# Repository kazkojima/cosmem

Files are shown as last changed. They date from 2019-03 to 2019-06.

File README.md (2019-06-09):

# cosmem

cosmem is a simple RAM/ROM/clock generator for COSMAC 1802 CPU, implemnted with TinyFPGA. An ancient chip meets FPGA :-)

spimemio.v is imported from the picorv32 example written by Clifford Wolf.

[board]

lv3v3/ is for kicad files of a level shifter board to interface 1802 and TinyFPGA.

picture of cosmaclv

within this enclosure

picture of cosmac box

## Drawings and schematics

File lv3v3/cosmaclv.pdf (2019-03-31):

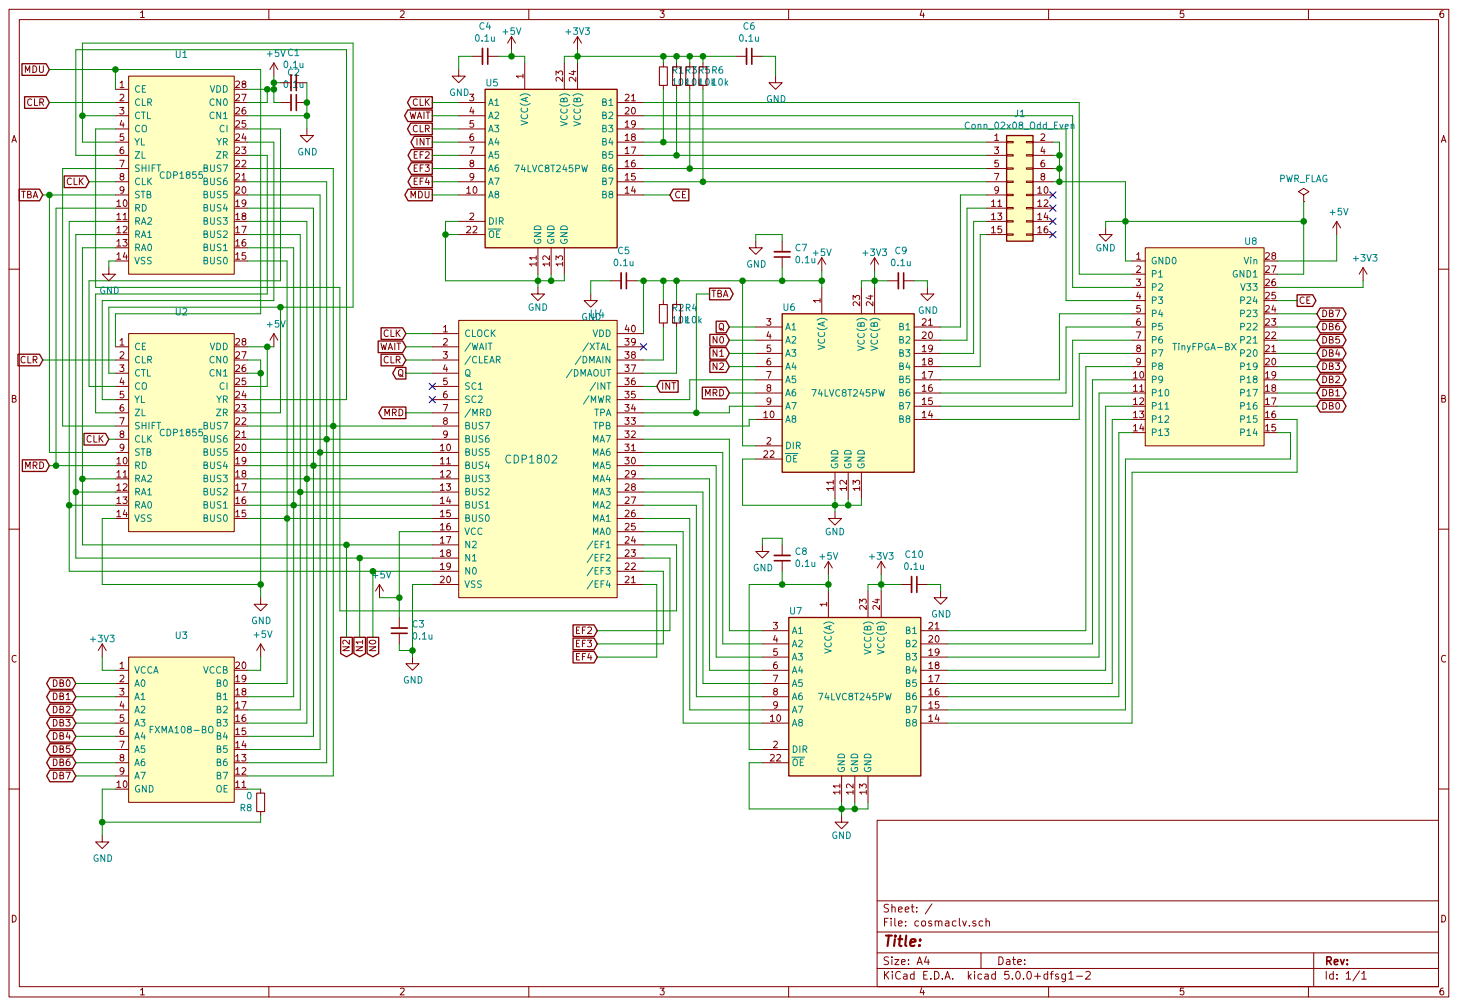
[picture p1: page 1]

J1 Conn_02x08_Odd_Even

9 | | | 10
11 | 12
13 | 14
15 | 16

Id: 1/1 Title: File: cosmaclv.sch Sheet: /

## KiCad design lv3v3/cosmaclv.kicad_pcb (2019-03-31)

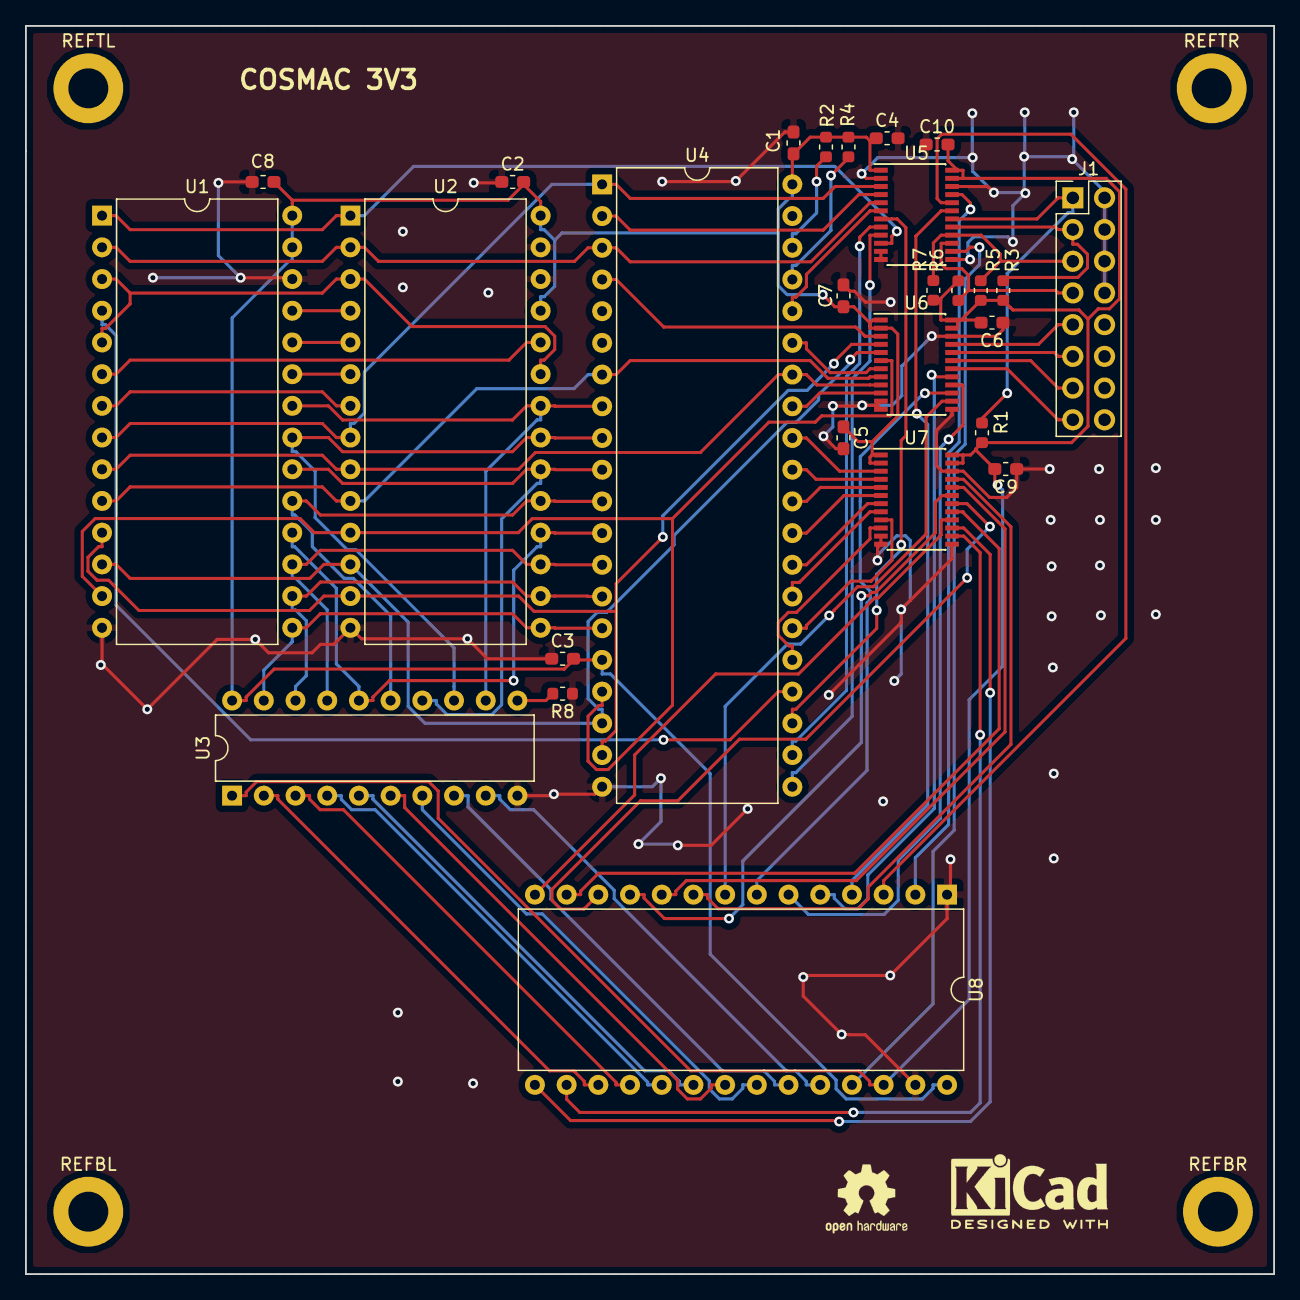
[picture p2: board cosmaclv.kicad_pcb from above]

Board: 2 copper layers, 100.0 x 100.0 mm, 31 parts (0 on the bottom side), 77 nets.

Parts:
C1, C2, C3, C4, C5, C6, C7, C8, C9, C10: 0.1u; C_0603_1608Metric_Pad1.05x0.95mm_HandSolder
J1: Conn_02x08_Odd_Even; PinHeader_2x08_P2.54mm_Vertical
R1, R2, R3, R4, R5, R6, R7: 10k; R_0603_1608Metric
R8: 0; R_0603_1608Metric
REFBL: MountingHole_3.2mm_M3_DIN965_Pad
REFBR: MountingHole_3.2mm_M3_DIN965_Pad
REFTL: MountingHole_3.2mm_M3_DIN965_Pad
REFTR: MountingHole_3.2mm_M3_DIN965_Pad
U1, U2: CDP1855; DIP-28_W15.24mm
U3: FXMA108-BO; DIP-20_W7.62mm
U4: CDP1802; DIP-40_W15.24mm
U5, U6, U7: 74LVC8T245PW; TSSOP-24_4.4x7.8mm_P0.65mm
U8: TinyFPGA-BX; DIP-28_W15.24mm

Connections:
+3V3: C6.2, C9.2, C10.2, R1.1, R3.1, R5.1, R6.1, R7.1, U3.1, U5.23, U5.24, U6.23, U6.24, U7.23, U7.24, U8.26
+5V: C1.2, C2.2, C3.2, C4.1, C5.1, C7.1, C8.1, R2.1, R4.1, U1.27, U1.28, U2.25, U2.28, U3.20, U4.16, U4.40, U5.1, U6.1, U6.2, U7.1, U7.2, U8.28
CE: U5.14, U8.25
CLK: U1.8, U2.8, U4.1, U5.3
CLR: U1.2, U2.2, U4.3, U5.5
DB0: U3.2, U8.17
DB1: U3.3, U8.18
DB2: U3.4, U8.19
DB3: U3.5, U8.20
DB4: U3.6, U8.21
DB5: U3.7, U8.22
DB6: U3.8, U8.23
DB7: U3.9, U8.24
EF2: U4.23, U5.7
EF3: U4.22, U5.8
EF4: U4.21, U5.9
GND: C1.1, C2.1, C3.1, C4.2, C5.2, C6.1, C7.2, C8.2, C9.1, C10.1, J1.2, J1.4, J1.6, J1.8, R8.1, U1.14, U1.26, U2.14, U2.26, U2.27, U3.10, U4.20, U5.2, U5.11, U5.12, U5.13, U5.22, U6.11, U6.12, U6.13, U6.22, U7.11, U7.12, U7.13, U7.22, U8.1, U8.27
INT: U4.36, U5.6
MDU: U1.1, U2.1, U5.10
MRD: U1.10, U2.10, U4.7, U6.8
N0: U1.11, U2.13, U4.19, U6.4
N1: U1.12, U2.12, U4.18, U6.5
N2: U1.13, U2.11, U4.17, U6.6
unnamed: J1.1, R1.2, U5.18
unnamed: J1.3, R3.2, U5.17
unnamed: J1.5, R5.2, R7.2, U5.16
unnamed: J1.7, R6.2, U5.15
unnamed: J1.9, U6.21
unnamed: J1.11, U6.20
unnamed: J1.13, U6.19
unnamed: J1.15, U6.18
unnamed: R2.2, U4.38
unnamed: R4.2, U4.37
unnamed: R8.2, U3.11
unnamed: U1.3, U1.5, U2.3, U2.23
unnamed: U1.4, U4.24
unnamed: U1.6, U2.24
unnamed: U1.7, U2.7
unnamed: U1.15, U2.15, U3.19, U4.15
unnamed: U1.16, U2.16, U3.18, U4.14
unnamed: U1.17, U2.17, U3.17, U4.13
unnamed: U1.18, U2.18, U3.16, U4.12
unnamed: U1.19, U2.19, U3.15, U4.11
unnamed: U1.20, U2.20, U3.14, U4.10
unnamed: U1.21, U2.21, U3.13, U4.9
unnamed: U1.22, U2.22, U3.12, U4.8
unnamed: U1.23, U2.6
unnamed: U1.24, U2.5
unnamed: U1.25, U2.4
unnamed: U4.25, U7.10
unnamed: U4.26, U7.9
unnamed: U4.27, U7.8
unnamed: U4.28, U7.7
unnamed: U4.29, U7.6
unnamed: U4.30, U7.5
unnamed: U4.31, U7.4
unnamed: U4.32, U7.3
unnamed: U4.33, U6.10
unnamed: U4.35, U6.7
unnamed: U5.19, U8.4
unnamed: U5.20, U8.3
unnamed: U5.21, U8.2
unnamed: U6.14, U8.8
unnamed: U6.15, U8.7
unnamed: U6.16, U8.6
unnamed: U6.17, U8.5
unnamed: U7.14, U8.16
unnamed: U7.15, U8.15
unnamed: U7.16, U8.14
unnamed: U7.17, U8.13
unnamed: U7.18, U8.12
unnamed: U7.19, U8.11
unnamed: U7.20, U8.10
unnamed: U7.21, U8.9
Q: U4.4, U6.3
TBA: U1.9, U2.9, U4.34, U6.9
WAIT: U4.2, U5.4
